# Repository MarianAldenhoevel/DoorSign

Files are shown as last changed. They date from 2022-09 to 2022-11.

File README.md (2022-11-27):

# DoorSign
A PCB to be used as door sign.

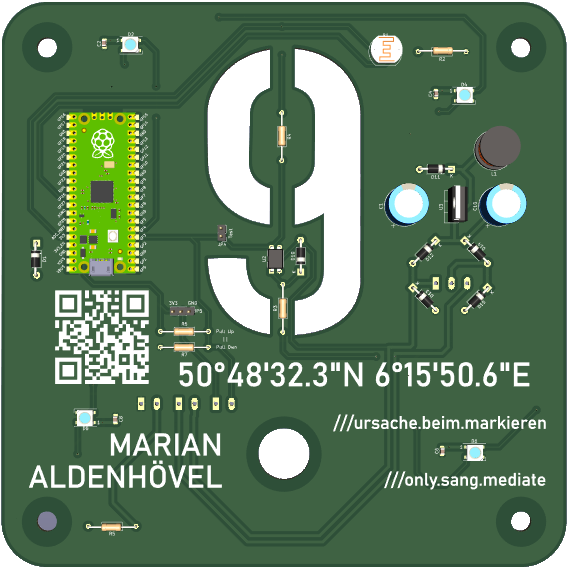
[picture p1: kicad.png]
KiCAD 3D view


* The board outline indicates the house number
* Silkscreen shows name and miscellanous information
* Mounting holes and hole for an illuminated ringer-button
* Footprints and layout to support a Raspberry Pi Pico (plain and W-version interchangeable), a LDR based light sensor, Neopixel LEDs and circuitry to detect a ringer-button press

Also firmware for the Pico to animate the LEDs suffering from feature-bloat. Guilty, pick a less capable chip next time.

Propably not useable directly by forking unless you happen to be me and live here. But if you find bits useful, go for it.

---
License:  
  
Creative Commons Attribution-ShareAlike  
CC BY-SA

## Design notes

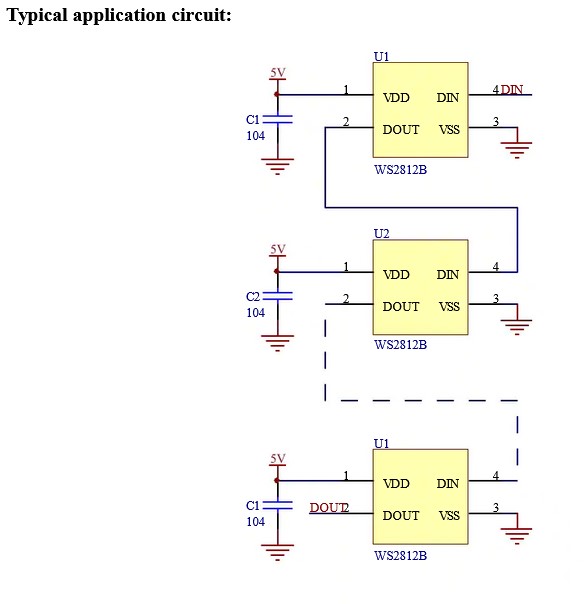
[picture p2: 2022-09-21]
Schematic-WS2812B.jpg

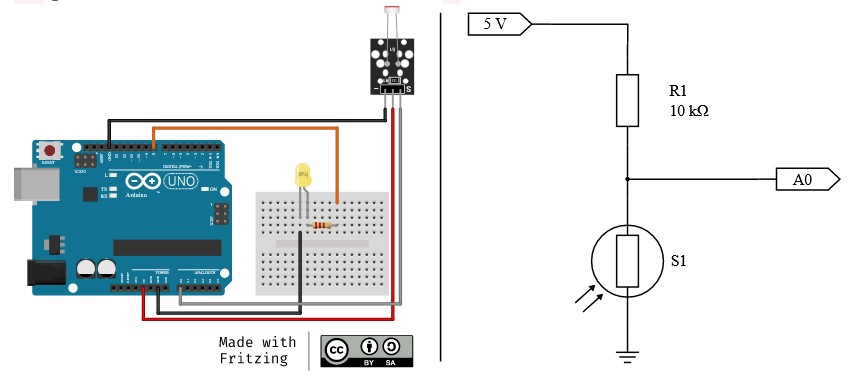
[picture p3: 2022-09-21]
Schematic-LDR_KY-018.jpg

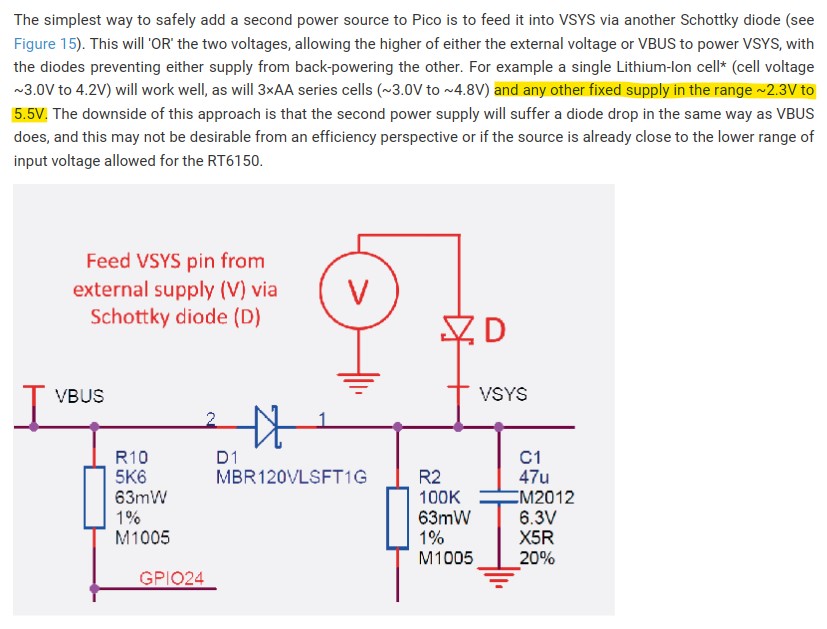
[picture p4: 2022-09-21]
Schematic-Pi Pico Power.jpg

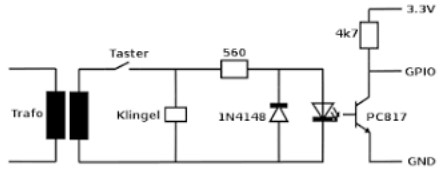
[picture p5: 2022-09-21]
Schematic-Klingeldetektor.jpg

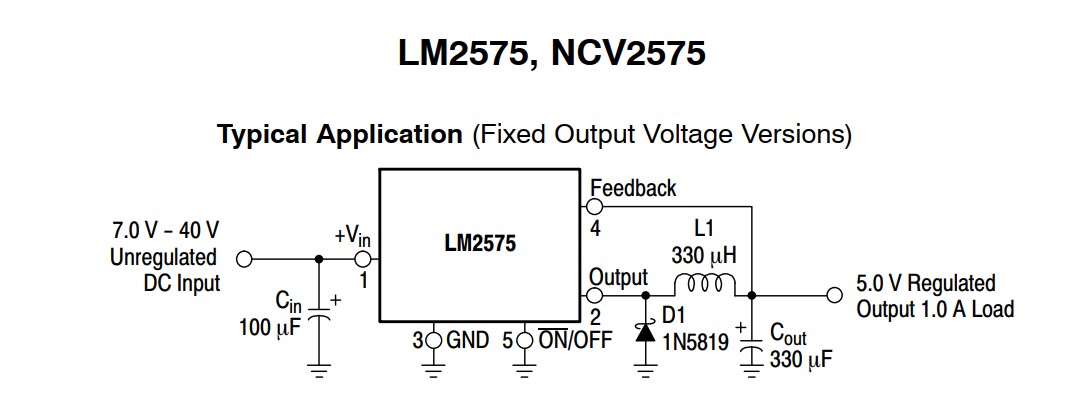
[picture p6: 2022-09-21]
Schematic-LM2575.jpg

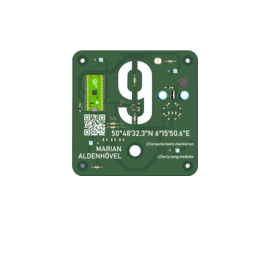
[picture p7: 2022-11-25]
Firmware/www/mstile-150x150.png

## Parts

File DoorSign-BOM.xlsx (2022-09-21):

Ref | Qnty | Value | Cmp name | Footprint | Description | Vendor | Vendor-Code
C1, C10, | 2 | 470uF | C_Polarized | Capacitor_THT:CP_Radial_D12.5mm_P5.00mm | Polarized capacitor | Reichelt | FM-A 470U 35
C2, C3, C4, C5, C6, C7, C8, C9, | 8 | 100nF | C | Capacitor_SMD:C_0805_2012Metric_Pad1.18x1.45mm_HandSolder | Unpolarized capacitor | Reichelt | KEM Z5U0805 100N
D1, | 1 | D_Schottky | D_Schottky | Diode_THT:D_DO-41_SOD81_P10.16mm_Horizontal | Schottky diode | Reichelt | SB 1100
D2, D3, D4, D5, D6, D7, D8, D9, | 8 | WS2812B | WS2812B | LED_SMD:LED_WS2812B_PLCC4_5.0x5.0mm_P3.2mm | RGB LED with integrated controller
D10, | 1 | 1N4148 | 1N4148 | Diode_THT:D_DO-41_SOD81_P10.16mm_Horizontal | 100V 0.15A standard switching diode, DO-35 | Reichelt | 1N 4148
D11, | 1 | 1N5819 | 1N5819 | Diode_THT:D_DO-41_SOD81_P10.16mm_Horizontal | 40V 1A Schottky Barrier Rectifier Diode, DO-41 | Reichelt | 1N 5819
D12, D13, D14, D15, | 4 | 1N4001 | 1N4001 | Diode_THT:D_DO-41_SOD81_P10.16mm_Horizontal | 50V 1A General Purpose Rectifier Diode, DO-41 | Reichelt | 1N 4001
J1, | 1 | Wall | Screw_Terminal_01x03 | TerminalBlock:TerminalBlock_Altech_AK300-3_P5.00mm | Generic screw terminal, single row, 01x03, script generated (kicad-library-utils/schlib/autogen/connector/) | Reichelt | CTB5202-3
J2, | 1 | Taster | Screw_Terminal_01x02 | TerminalBlock:TerminalBlock_Altech_AK300-2_P5.00mm | Generic screw terminal, single row, 01x02, script generated (kicad-library-utils/schlib/autogen/connector/) | Reichelt | CTB5202-2
J3, | 1 | Taster-LED | Screw_Terminal_01x02 | TerminalBlock:TerminalBlock_Altech_AK300-2_P5.00mm | Generic screw terminal, single row, 01x02, script generated (kicad-library-utils/schlib/autogen/connector/) | Reichelt | CTB5202-2
L1, | 1 | 330uH | L | Inductor_THT:L_Axial_L5.0mm_D3.6mm_P10.00mm_Horizontal_Murata_BL01RN1A2A2 | Inductor | Reichelt | L-09HVP 330µ
R1, | 1 | LDR03 | LDR03 | OptoDevice:R_LDR_10x8.5mm_P7.6mm_Vertical | light dependent resistor | Conrad | 1762910 - NA
R2, | 1 | 10k | R | Resistor_THT:R_Axial_DIN0207_L6.3mm_D2.5mm_P15.24mm_Horizontal | Resistor | Reichelt | 1/4W 10K
R4, R5, | 2 | 100k | R | Resistor_THT:R_Axial_DIN0207_L6.3mm_D2.5mm_P15.24mm_Horizontal | Resistor | Reichelt | 1/4W 100K
R3, | 1 | 330 | R | Resistor_THT:R_Axial_DIN0207_L6.3mm_D2.5mm_P15.24mm_Horizontal | Resistor | Reichelt | 1/4W 330
U1, | 1 | Pico | Pico | MCU_RaspberryPi_and_Boards:RPi_Pico_SMD_TH | MCU | Reichelt | RASP PI PICO
U2, | 1 | PC817 | PC817 | Package_DIP:DIP-4_W7.62mm | DC Optocoupler, Vce 35V, CTR 50-300%, DIP-4 | Reichelt | LTV 817
U3, | 1 | LM2575-5.0BT | LM2575-5.0BT | Package_TO_SOT_THT:TO-220-5_Vertical | Fixed 5.0V 52kHz Simple 1A Buck Regulator, TO-220-5 | Reichelt | LM2575T-5G

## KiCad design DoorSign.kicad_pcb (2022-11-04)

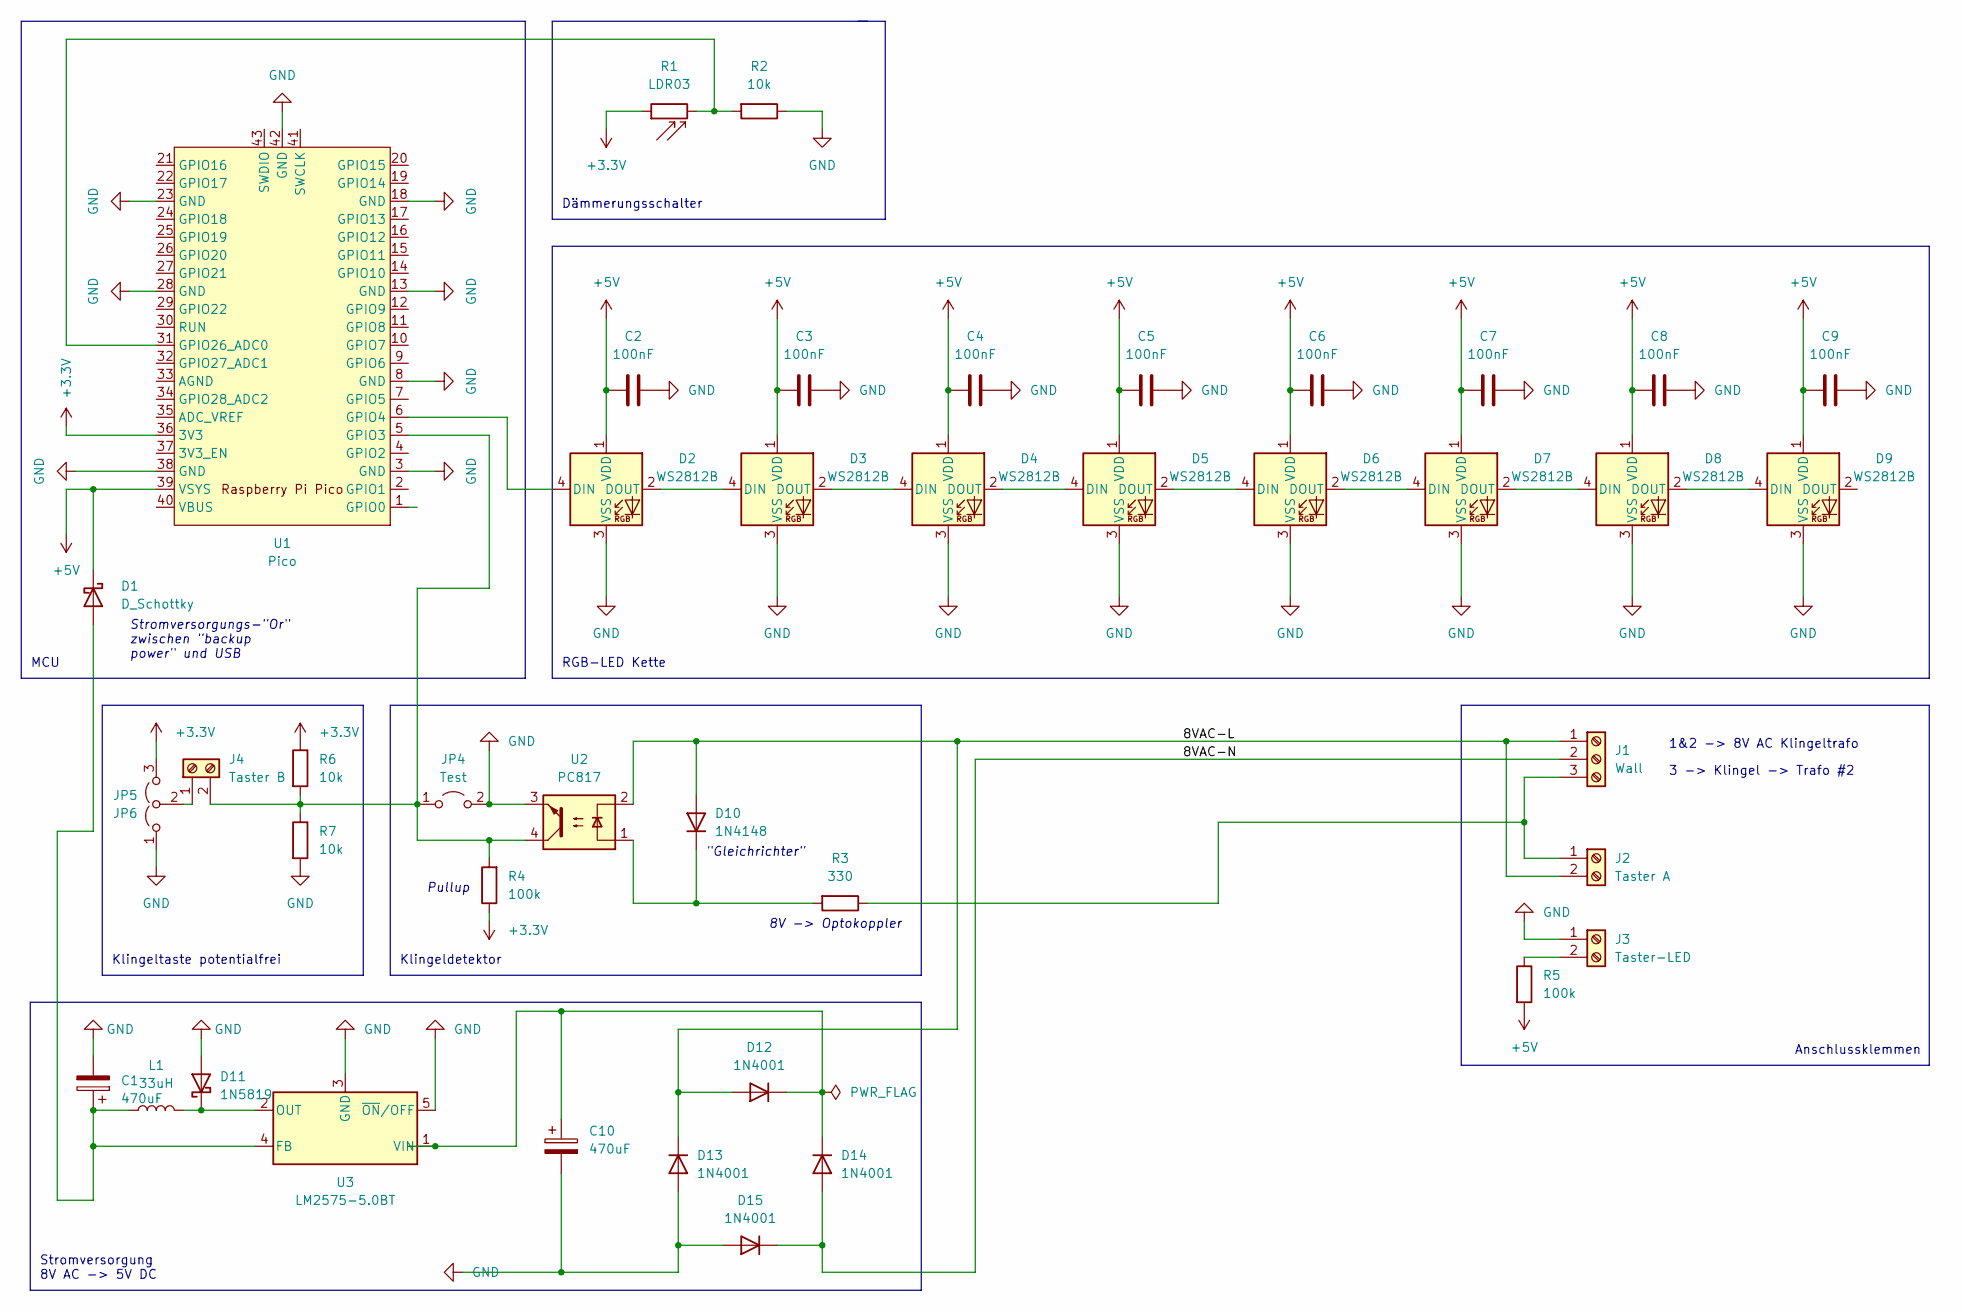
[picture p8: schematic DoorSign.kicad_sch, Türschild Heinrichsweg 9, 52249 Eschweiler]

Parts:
C1, C10: 470uF; CP_Radial_D12.5mm_P5.00mm
C2, C3, C4, C5, C6, C7, C8, C9: 100nF; C_0805_2012Metric_Pad1.18x1.45mm_HandSolder
D1: D_Schottky; D_DO-41_SOD81_P10.16mm_Horizontal
D2, D3, D4, D5, D6, D7, D8, D9: WS2812B; LED_WS2812B_PLCC4_5.0x5.0mm_P3.2mm
D10: 1N4148; D_DO-41_SOD81_P10.16mm_Horizontal
D11: 1N5819; D_DO-41_SOD81_P10.16mm_Horizontal
D12, D13, D14, D15: 1N4001; D_DO-41_SOD81_P10.16mm_Horizontal
J1: Wall; TerminalBlock_Altech_AK300-3_P5.00mm
J2: Taster A; TerminalBlock_Altech_AK300-2_P5.00mm
J3: Taster-LED; TerminalBlock_Altech_AK300-2_P5.00mm
J4: Taster B; TerminalBlock_Altech_AK300-2_P5.00mm
JP4: Test; PinHeader_1x02_P2.54mm_Vertical
JP5: JP6; PinHeader_1x03_P2.54mm_Vertical
L1: 33uH; L_Radial_D12.5mm_P7.00mm_Fastron_09HCP
R1: LDR03; R_LDR_10x8.5mm_P7.6mm_Vertical
R2, R6, R7: 10k; R_Axial_DIN0207_L6.3mm_D2.5mm_P15.24mm_Horizontal
R3: 330; R_Axial_DIN0207_L6.3mm_D2.5mm_P15.24mm_Horizontal
R4, R5: 100k; R_Axial_DIN0207_L6.3mm_D2.5mm_P15.24mm_Horizontal
U1: Pico; RPi_Pico_SMD_TH
U2: PC817; DIP-4_W7.62mm
U3: LM2575-5.0BT; TO-220-5_Vertical

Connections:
+3.3V: JP5.3 (B), R1.1, R4.1, R6.1, U1.36 (3V3)
+5V: C2.2, C3.2, C4.2, C5.2, C6.2, C7.2, C8.2, C9.2, D1.1 (K), D2.1 (VDD), D3.1 (VDD), D4.1 (VDD), D5.1 (VDD), D6.1 (VDD), D7.1 (VDD), D8.1 (VDD), D9.1 (VDD), R5.2, U1.39 (VSYS)
/8VAC-L: D10.2 (A), D12.2 (A), D13.1 (K), J1.1, J2.2, U2.2
/8VAC-N: D14.2 (A), D15.1 (K), J1.2
GND: C1.2, C2.1, C3.1, C4.1, C5.1, C6.1, C7.1, C8.1, C9.1, C10.2, D2.3 (VSS), D3.3 (VSS), D4.3 (VSS), D5.3 (VSS), D6.3 (VSS), D7.3 (VSS), D8.3 (VSS), D9.3 (VSS), D11.2 (A), D13.2 (A), D15.2 (A), J3.1, JP4.2 (B), JP5.1 (A), R2.1, R7.2, U1.3 (GND), U1.8 (GND), U1.13 (GND), U1.18 (GND), U1.23 (GND), U1.28 (GND), U1.38 (GND), U1.42 (GND), U2.3, U3.3 (GND), U3.5 (~ON/OFF)
unnamed: C1.1, D1.2 (A), L1.1, U3.4 (FB)
unnamed: C10.1, D12.1 (K), D14.1 (K), U3.1 (VIN)
unnamed: D2.2 (DOUT), D3.4 (DIN)
unnamed: D2.4 (DIN), U1.6 (GPIO4)
unnamed: D3.2 (DOUT), D4.4 (DIN)
unnamed: D4.2 (DOUT), D5.4 (DIN)
unnamed: D5.2 (DOUT), D6.4 (DIN)
unnamed: D6.2 (DOUT), D7.4 (DIN)
unnamed: D7.2 (DOUT), D8.4 (DIN)
unnamed: D8.2 (DOUT), D9.4 (DIN)
unnamed: D10.1 (K), R3.2, U2.1
unnamed: D11.1 (K), L1.2, U3.2 (OUT)
unnamed: J1.3, J2.1, R3.1
unnamed: J3.2, R5.1
unnamed: J4.1, JP5.2 (C)
unnamed: J4.2, JP4.1 (A), R4.2, R6.2, R7.1, U1.5 (GPIO3), U2.4
unnamed: R1.2, R2.2, U1.31 (GPIO26_ADC0)

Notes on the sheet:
Klingeltaste potentialfrei
RGB-LED Kette
Anschlussklemmen
1&2 -> 8V AC Klingeltrafo
8V -> Optokoppler
"Gleichrichter"
Stromversorgung 8V AC -> 5V DC
3 -> Klingel -> Trafo #2
Pullup
Klingeldetektor
MCU
Dämmerungsschalter
Stromversorgungs-"Or" zwischen "backup power" und USB

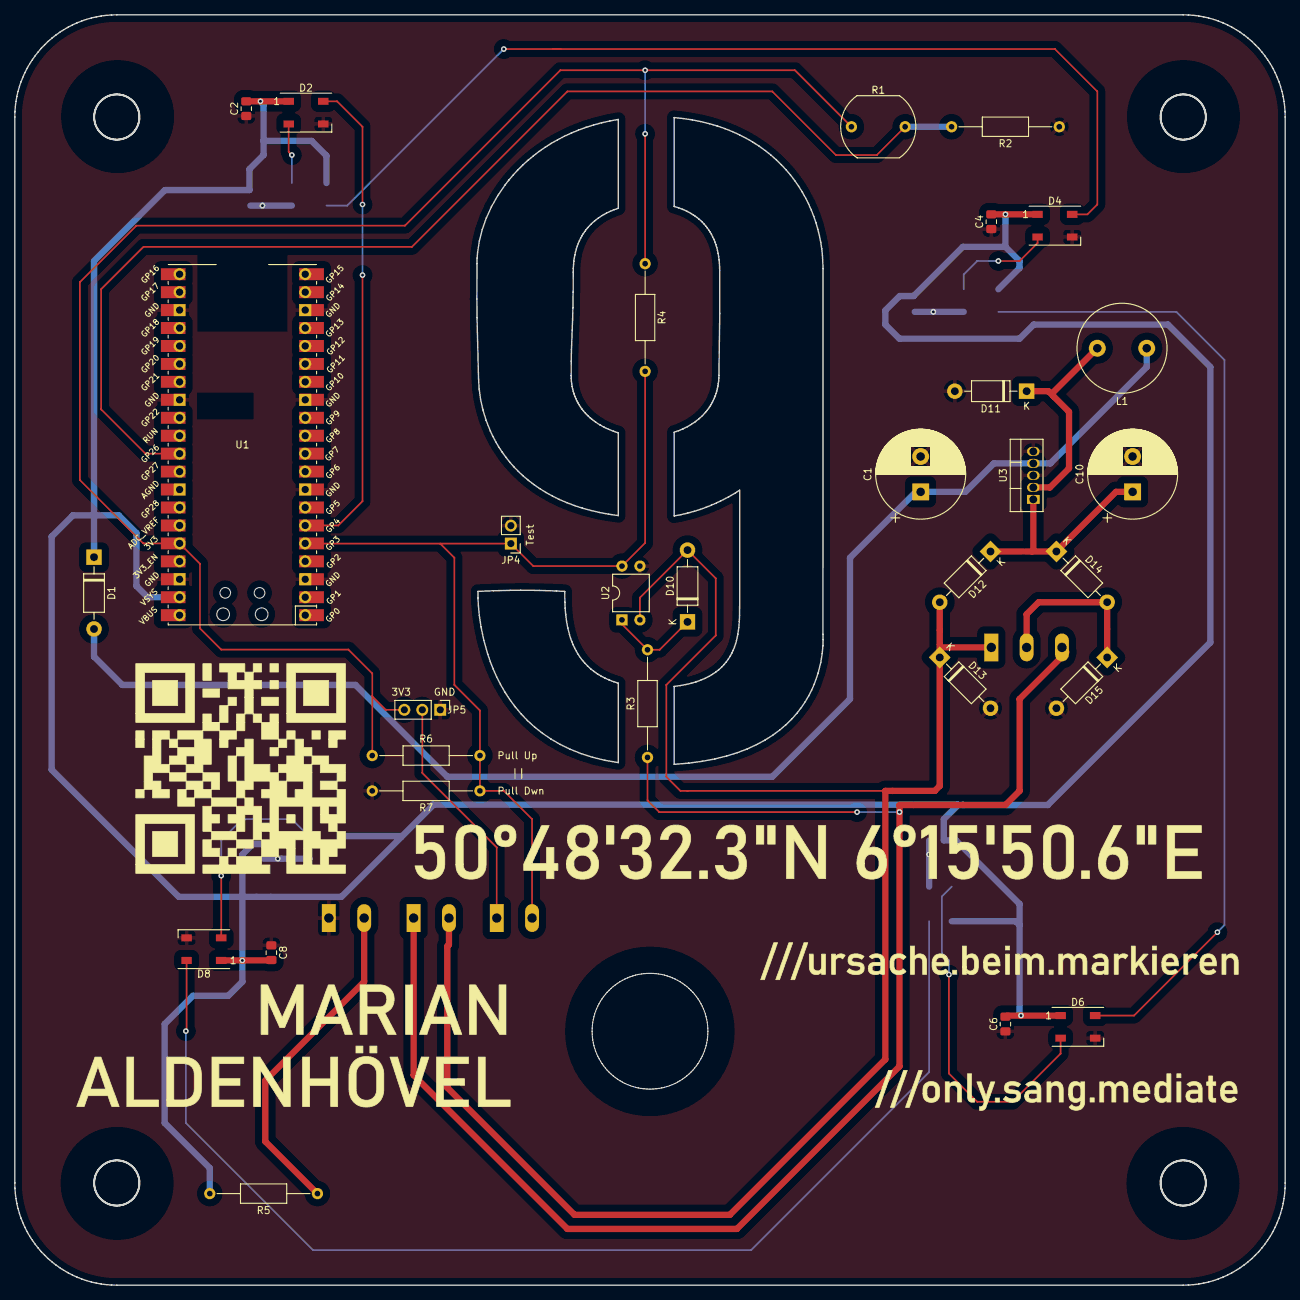
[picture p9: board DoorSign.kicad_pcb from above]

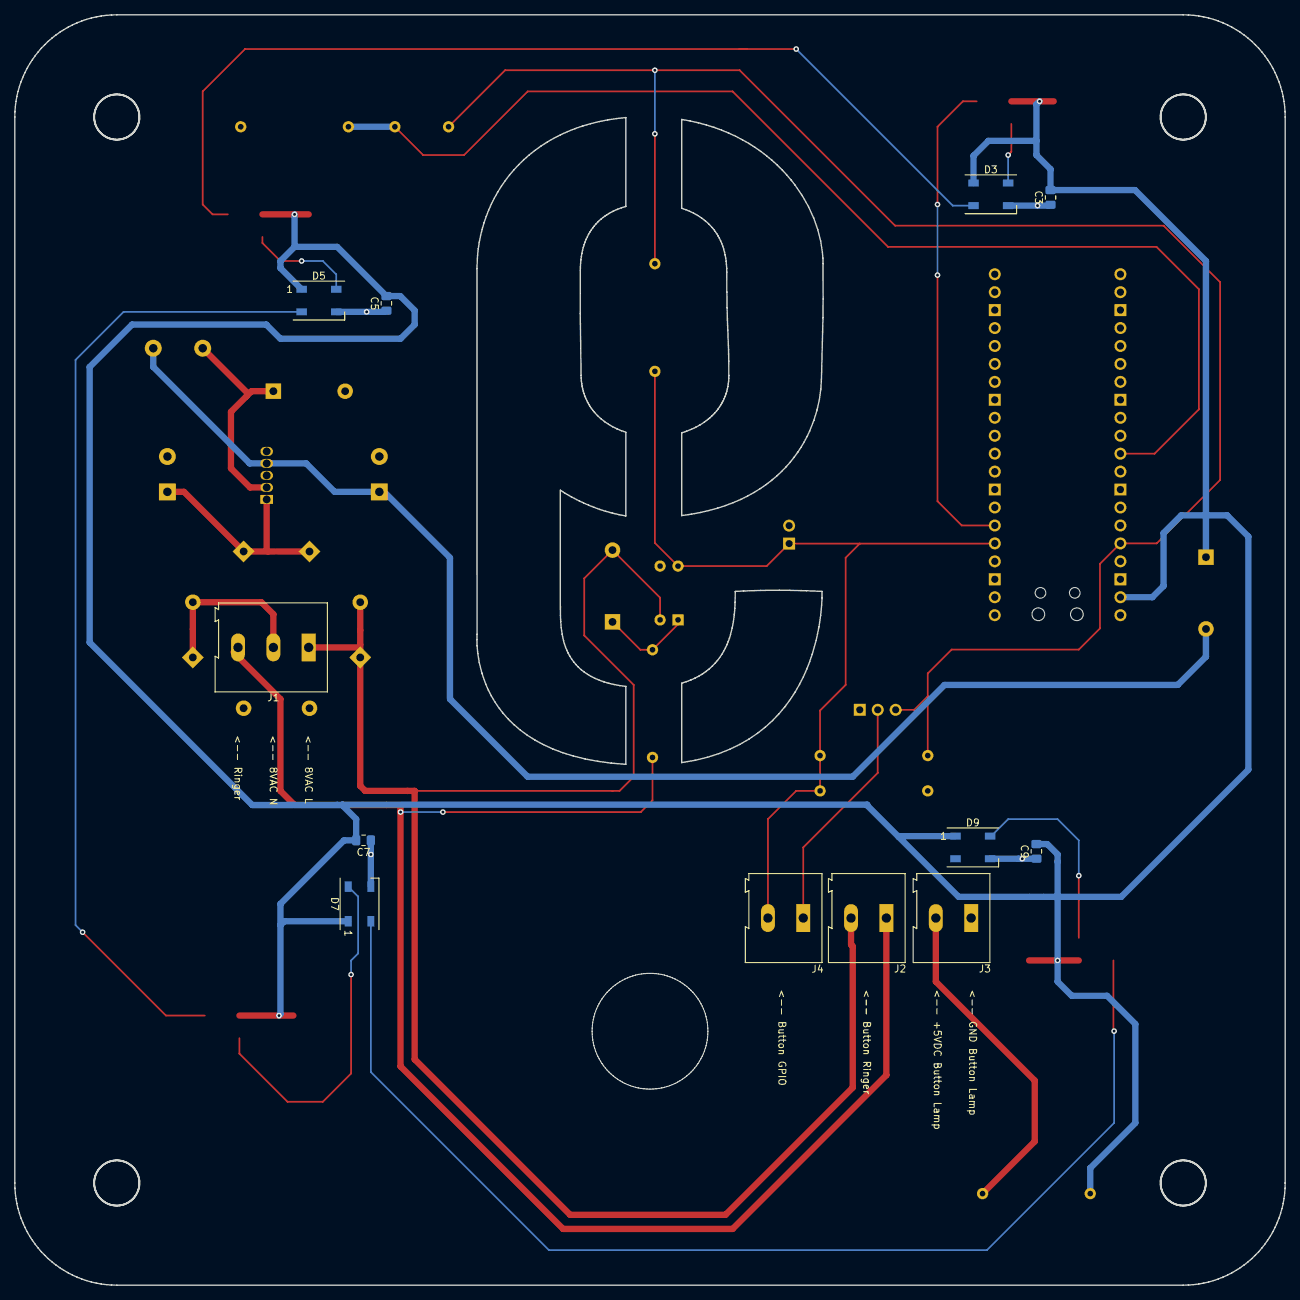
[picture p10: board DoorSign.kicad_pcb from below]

Board: 2 copper layers, 179.8 x 179.8 mm, 42 parts (12 on the bottom side), 22 nets.

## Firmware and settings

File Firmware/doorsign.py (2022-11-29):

'''
This module implements access to the pixels on the board. It also defines
some support functions for color-management, blending et al.

The general API is to wrap update in beginUpdate() and endUpdate() calls
which may be nested. The first call to beginUpdate() aqcuires a lock. The 
last call to endUpdate() sends the data to the LEDs and then releases the
lock.

So make sure you try..finally every one of them!
'''

firmware_version = '0.3'
pixel_count = 8 # Hardware-Config: Number of pixels on the board.
framerate = 25 # Frames/s for animations.

gamma = 2.8

import machine
import math
import time
import random
from machine import Pin
from neopixel import NeoPixel
import _thread
import lock
import logger

# Set up gamma correction lookup table.
_gamma_table = []

for input in range(256):
    output = math.trunc((((input / 255) ** gamma) * 255) + 0.5)
    _gamma_table.append(output)

_pixel_lock = lock.RecursiveLock()

_rawpixels = [(0, 0, 0)] * pixel_count
_np = NeoPixel(machine.Pin(4, machine.Pin.OUT), pixel_count)

_adc_pins = [
    machine.ADC(26), # ADC0
    machine.ADC(28), # ADC1
    machine.ADC(28)  # ADC2
]

frame_intervall_ms = 1000//framerate # How many ms per frame?

manual_control = False

def beginUpdate():
    _pixel_lock.acquire()
    
def endUpdate():
    assert _pixel_lock.mine() # If not someone has not wrapped their begin-/endUpdate-calls correctly. 
    
    # Safe to query the lock. It is ours. If we are about to actually unlock send the final
    # pixel data out.
    if _pixel_lock.count() == 1:
        _np.write()
        
    _pixel_lock.release()

def setManualControl(manual):
    global manual_control
    
    _pixel_lock.acquire()
    try:
        manual_control = manual
    finally:
        _pixel_lock.release()

def readADC():
    result = []
    for pin in _adc_pins:
        result.append(pin.read_u16())

    return result

'''
Convert from RGB color space to HSV. 
RGB is a tuple of three integers in the range 0..255. 
HSV is returned as a tuple of integers (0..360, 0..100, 0..100)
'''
def RGBToHSV(rgb_color):

    (r, g, b) = rgb_color
    r = r/255.0
    g = g/255.0
    b = b/255.0
    high = max(r, g, b)
    low = min(r, g, b)
    h, s, v = high, high, high

    d = high - low
    s = 0 if high == 0 else d/high

    if high == low:
        h = 0.0
    else:
        h = {
            r: (g - b) / d + (6 if g < b else 0),
            g: (b - r) / d + 2,
            b: (r - g) / d + 4,
        }[high]
        h /= 6

    h = math.trunc(360 * h)
    s = math.trunc(100 * s)
    v = math.trunc(100 * v)

    return h, s, v

'''
Convert from HSV color space to RGB. 
HSV is a tuple of integers (0..360, 0..100, 0..100)
RGB is returned as a tuple of three integers in the range 0..255. 
'''
def HSVToRGB(hsv_color):
    
    (h, s, v) = hsv_color
    h = h/360.0
    s = s/100.0
    v = v/100.0
    
    i = math.floor(h*6)
    f = h*6 - i
    p = v * (1-s)
    q = v * (1-f*s)
    t = v * (1-(1-f)*s)

    r, g, b = [
        (v, t, p),
        (q, v, p),
        (p, v, t),
        (p, q, v),
        (t, p, v),
        (v, p, q),
    ][int(i%6)]
    
    r = math.trunc(255 * r)
    g = math.trunc(255 * g)
    b = math.trunc(255 * b)
    
    return r, g, b

def randomColor():
    return HSVToRGB((random.randint(0,360), 255, random.randint(5,255)))

def clamp(channel, min=0, max=255):
    if channel < min:
        channel = min
    elif channel > max:
        channel = max
        
    return channel

'''
Scale the channels of pixel by a floating point scalefactor. The factor is arbitrary,
the results are truncated and clamped.
'''
def scalePixel(pixel, scalefactor):
    return (
        clamp(math.trunc(pixel[0] * float(scalefactor))),
        clamp(math.trunc(pixel[1] * float(scalefactor))),
        clamp(math.trunc(pixel[2] * float(scalefactor)))
    )

'''
Scale all pixels by a floating point scalefactor. The factor is arbitrary,
the results are truncated and clamped.
'''
def scalePixels(pixels , scalefactor):
    result = [(0, 0, 0)] * pixel_count
    for pixelIndex in range(pixel_count):
        result[pixelIndex] = scalePixel(pixels[pixelIndex], scalefactor)
        
    return result

''' 
Linear blend between two single pixels, blend is a float between 0 and 1.
'''
def blendPixelLinear(pixel1, pixel2, blend):
    
    # Clamp blend value
    if blend < 0.0:
        blend = 0.0
    elif blend > 1.0:
        blend = 1.0

    return (
        math.trunc(pixel1[0] * (1.0-blend) + pixel2[0] * blend),
        math.trunc(pixel1[1] * (1.0-blend) + pixel2[1] * blend),
        math.trunc(pixel1[2] * (1.0-blend) + pixel2[2] * blend)
    )
        
'''
Linear blend between two complete pixel arrays, blend is a float between 0 and 1.
'''
def blendPixelsLinear(pixels1, pixels2, blend):
    result = [(0, 0, 0)] * pixel_count
    for pixelIndex in range(pixel_count):
        result[pixelIndex] = blendPixelLinear(pixels1[pixelIndex], pixels2[pixelIndex], blend)
        
    return result

''' 
More clever blend between two single pixels, blend is a float between 0 and 1.

The blend happens in HSV space with H going the "short way".
'''
def blendPixel(pixel1, pixel2, blend):
    
    # Clamp blend value
    if blend < 0.0:
        blend = 0.0
    elif blend > 1.0:
        blend = 1.0

    # Convert pixels to HSV space.
    hsv1 = RGBToHSV(pixel1)
    hsv2 = RGBToHSV(pixel2)
    
    # print('hsv1 ' + str(hsv1))
    # print('hsv2 ' + str(hsv2))
    
    # Swap so that Pixel2 has the larger H value.
    if hsv1[0] > hsv2[0]:
        hsv1, hsv2 = hsv2, hsv1 # Very pythonic swap.
        blend = 1.0 - blend;
  
    # The hue value wraps around at 360. We want it to blend along the
    # shortest arc. If the direct difference is greater than 180 go
    # the other way.
    if hsv2[0] - hsv1[0] > 180:
        h = (hsv1[0] + 360) * (1.0 - blend) + hsv2[0] * blend
        if h > 360:
            h -= 360
    else:
        h = hsv1[0] * (1.0 - blend) + hsv2[0] * blend
    
    # Blend S and V linearly.
    hsv = (
        math.trunc(h),
        math.trunc(hsv1[1] * (1.0-blend) + hsv2[1] * blend),
        math.trunc(hsv1[2] * (1.0-blend) + hsv2[2] * blend)
    )
    
    # print('hsv  ' + str(hsv))
    
    # Return as RBG value
    return HSVToRGB(hsv)

'''
More clever blend between two single pixels, blend is a float between 0 and 1.

The blend happens in HSV space with H going the "short way".
'''
def blendPixels(pixels1, pixels2, blend):
    result = [(0, 0, 0)] * pixel_count
    for pixelIndex in range(pixel_count):
        result[pixelIndex] = blendPixel(pixels1[pixelIndex], pixels2[pixelIndex], blend)
        
    return result

''' 
Set a single pixel.
'''            
def setPixel(pixelIndex, pixel):
    beginUpdate()
    try:
        # Store the raw rgb value for reading back.
        _rawpixels[pixelIndex] = pixel

        # Gamma-correct the RGB values.
        gammapixel = (_gamma_table[pixel[0]], _gamma_table[pixel[1]], _gamma_table[pixel[2]])

        # Send the corrected values to the hardware.
        _np[pixelIndex] = gammapixel
    finally:
        endUpdate()

'''
Update all pixels from an array.
'''    
def setPixels(pixels):
    beginUpdate()
    try:
        for pixelIndex in range(pixel_count):
            setPixel(pixelIndex, pixels[pixelIndex])            
    finally:
        endUpdate()        

''' 
Read a single pixel.
'''            
def getPixel(pixelIndex):
    return _rawpixels[pixelIndex]
        
'''
Read all pixels.
'''    
def getPixels():
    beginUpdate()
    try:
        pixels = [(0,0,0)] * pixel_count
        for pixelIndex in range(pixel_count):
            pixels[pixelIndex] = getPixel(pixelIndex)            
    finally:
        endUpdate()
        
    return pixels

'''
Turn all pixels off
'''        
def off():
    pixels = [(0, 0, 0)] * pixel_count
    setPixels(pixels)

'''
Print a single pixel as a six-digit hex string.
'''
def formatPixel(pixel):
    return pixel[0].to_bytes(1, 'big').hex() + pixel[1].to_bytes(1, 'big').hex() +pixel[2].to_bytes(1, 'big').hex()

'''
Format a pixel array for string output.
'''
def formatPixels(pixels):
    return '<' + ','.join([formatPixel(pixel) for pixel in pixels]) + '>'

if __name__ == '__main__':

    logger.write('__main__: All pixels off')
    off()
    
    print(_gamma_table)

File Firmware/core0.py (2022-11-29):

'''
This implements the network task.

Sets up WiFi as STA (Client) or AP (Access point) as _configured in _config.json

If set up as AP also runs a DNS server to implement a captive portal. The implementation
of that is right here and trivial.

Then it starts a primitive web server also implemented here. The web server supports
delivery of static resources and API endpoints all hardcoded.

The network task controls the _onboard LED. When setting up the LED is on, when setup
is completed sucessfully it turns off. If an error is encountered connecting in STA mode
a code is blinked. 

In operation the onboard LED turns on while network requests are being serviced.
'''

import rp2
import os
import machine
import network
import ubinascii
import time
import socket
import select
import ujson
import watchdog
import struct
import core1
import logger
import doorsign

_onboard = machine.Pin('LED', machine.Pin.OUT)
_myip = None
_config = None
_nextNTPSync = None
_boot_ms = time.ticks_ms()

def setup():
    global _config
    
    # Load _configuration
    logger.write('Reading config.json')
    with open('config.json') as fp:
        _config = ujson.load(fp)
    
'''
When the task fails to make a connection it blinks an error code on the
onboard LED
'''
def fatalConnectionError(code, message):
    _onboard.off()
    logger.write('FATAL: ' + str(code) + ' - ' + message)
    
    time.sleep(1)
    for _ in range(code):
        _onboard.on()
        time.sleep(0.5)
        _onboard.off()
        time.sleep(0.5)
        
    raise RuntimeError(message)    

'''
Single function to handle a DNS request.

Packet decoding adapted from #https://stackoverflow.com/questions/65060776/reading-dns-packet-in-python

We decode the request just for giggles. We don't even use it and always respond the same.
'''

OpCodeStrs = [
        'QUERY', 
        'IQUERY', 
        'STATUS', 
        '(reserved)', 
        'NOTIFY', 
        'UPDATE'
]

RCodeStrs = [
    'No Error', 
    'Format Error', 
    'Server Failure', 
    'Name Error', 
    'Not Implemented', 
    'Refused', 
    'XY Domain', 
    'XY RR Set', 
    'NX RR Set', 
    'Not Auth', 
    'Not Zone'
]
    
def handleDNS(socket):
    try:
        _onboard.on()

        request, client = socket.recvfrom(1024) # Big enough for anyone?

        # Decode DNS header.
        l = len(request)
        dnsDict = dict(
            ID      = request[0]*256+request[1],
            QR      = bool(request[2] & int('10000000', 2)),
            Opcode  =     (request[2] & int('01111000', 2))>>3,            
            AA      = bool(request[2] & int('00000100', 2)),
            TC      = bool(request[2] & int('00000010', 2)),
            RD      = bool(request[2] & int('00000001', 2)),
            RA      = bool(request[3] & int('10000000', 2)),
            Z       =     (request[3] & int('01110000', 2)),
            RCode   =     (request[3] & int('00001111', 2)),
            QDCOUNT = request[4]*256+request[5],
            ANCOUNT = request[6]*256+request[7],
            NSCOUNT = request[8]*256+request[9],
            ARCOUNT = request[10]*256 + request[11],
            # --
            QTYPE   = request[l-4]*256+request[l-3],
            QCLASS  = request[l-2]*256+request[l-2]
        )

        # Decode some values to strings.
        OpCode = dnsDict['Opcode']
        if (OpCode >= 0) and (OpCode < len(OpCodeStrs)):
            dnsDict['OpcodeStr'] = OpCodeStrs[OpCode]
        else:
            dnsDict['OpcodeStr'] = str(OpCode) + '?'
            
        RCode = dnsDict['RCode']
        if (RCode >= 0) and (RCode < len(RCodeStrs)):
            dnsDict['RCodeStr'] = RCodeStrs[RCode]
        else:
            dnsDict['RCodeStr'] = str(RCode) + '?'

        # Parse QNAME starting at byte #12.        
        n = 12
        qname = ''
        
        # Get field size.
        argSize = int(request[n])
        n += 1
        
        # Are there more fields?
        while (argSize != 0) and (n < len(request)):
            # Yes. Extract the substring and apped a period.
            qname += request[n:n+argSize].decode() + '.'
            n += argSize
                
            # Get next field size.
            argSize = int(request[n])
            n += 1
            
        dnsDict['QNAME'] = qname[:-1] # Chop off extra period we have added.

        logger.write('DNS query for \"' + dnsDict['QNAME'] + '\" from ' + client[0])

        # Build the response.
        response = bytearray()
        response = request[:2] 							# Request ID
        response += b'\x81\x80' 						# Response flags
        response += request[4:6] + request[4:6] 		# QD/AN count
        response += b'\x00\x00\x00\x00' 				# NS/AR count
        response += request[12:] 						# Original request body
        response += b'\xC0\x0C' 						# Pointer to domain name at byte 12
        response += b'\x00\x01\x00\x01' 				# Type and class (A record / IN class)
        response += b'\x00\x00\x00\x3C' 				# Time to live 60 seconds
        response += b'\x00\x04' 						# Response length (4 bytes = 1 ipv4 address)
        response += bytes(map(int, _myip.split('.'))) 	# IP address parts
        
        # And deliver it.
        socket.sendto(response, client)

    except Exception as e:
        logger.write('Error handling DNS request ' + str(e))

    finally:
        _onboard.off()

'''
Build a representation of the sensors and led settings
'''

def pluralize(n, unit):
    if n == 0:
        return ''
    elif n == 1:
        return '1 ' + unit + ' '
    else:
        return str(n) + ' ' + unit + 's '

def apiData():
    result = {}
    
    doorsign.beginUpdate()
    try:
        # Get filesystem information.
        v = os.statvfs('/')
        size_bytes = v[1]*v[2]
        free_bytes = v[0]*v[3]
        
        # Get uptime. May wrap around and give values that are too short.
        ticks = time.ticks_diff(time.ticks_ms(), _boot_ms)
        s, ms = divmod(ticks, 1000)
        m, s = divmod(s, 60)
        h, m = divmod(m, 60)
        d, h = divmod(h, 24)
        
        result['uptime'] = (pluralize(d, 'day') + pluralize(h, 'hour') + pluralize(m, 'minute') + pluralize(s, 'second')).strip()
        result['firmware_version'] = doorsign.firmware_version
        result['manual_control'] = doorsign.manual_control
        result['pixels'] = [{'R': p[0], 'G': p[1], 'B': p[2]} for p in doorsign.getPixels()]            
        result['adc'] = doorsign.readADC()
        result['animations'] = [a.__name__ for a in core1.animations]
        result['active_animation'] = (core1.active_animation.__name__ if core1.active_animation else None);
        result['size_bytes'] = size_bytes
        result['free_bytes'] = free_bytes
    finally:
        doorsign.endUpdate()
    
    return result
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

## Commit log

2022-09-19 Initial import
    [DoorSign.kicad_pcb, DoorSign.kicad_sch]
2022-09-21 Added BOM and partial schematics
    [DoorSign-BOM.xlsx, DoorSign.kicad_pcb, DoorSign.kicad_sch]
2022-10-05 added jumper for optocoupler
    [DoorSign.kicad_pcb, DoorSign.kicad_sch]
2022-10-05 connected all GND pins on the Pico
    [DoorSign.kicad_pcb, DoorSign.kicad_sch]
2022-10-05 Attempt to fix ERC message
    [DoorSign.kicad_sch]
2022-10-21 Rewired GPIOs for compatibility with Raspberry Pi Pico W
    [DoorSign.kicad_pcb, DoorSign.kicad_sch]
2022-10-21 Modified footprints for compatibility with Pi Pico W
    [DoorSign.kicad_pcb]
2022-11-04 Potential free contactor and pull-up/down added
    [DoorSign.kicad_pcb, DoorSign.kicad_sch]
2022-11-04 Jumpers for potential free contact
    [DoorSign.kicad_pcb, DoorSign.kicad_sch]
2022-11-24 Added Pico Firmware
    [DoorSign.kicad_sch]
2022-11-25 Repair after FS crash
    [core1.py, doorsign.py, logger.py]
2022-11-26 Fixes after refactoring. Support for hardware WDT
    [animation_random_mixed.py, core0.py, core1.py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]
2022-11-26 API and UI to switch animation
2022-11-27 added kicad.png
2022-11-27 Tests, debugging and fixes
    [core0.py, core1.py, main.py]
